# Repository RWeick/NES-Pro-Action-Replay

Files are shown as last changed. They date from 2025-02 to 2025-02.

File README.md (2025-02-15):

# NES-Pro-Action-Replay
Everything necessary to produce the Pro Action Replay for the NES. Happy making.

The PAL's logic decodes to:

/SRAM.CS1.OE = ROMSEL.Sys and Addr: 0x5000 - 0x5FFF

/CPU_FF_CLK = /ROMSEL.Sys and PPU_EN and Addr: 0x7FFA

/PPU_FF_CLK = /ROMSEL.Sys and Addr: 0x7FF8

PCB Thickness: 1.6 mm

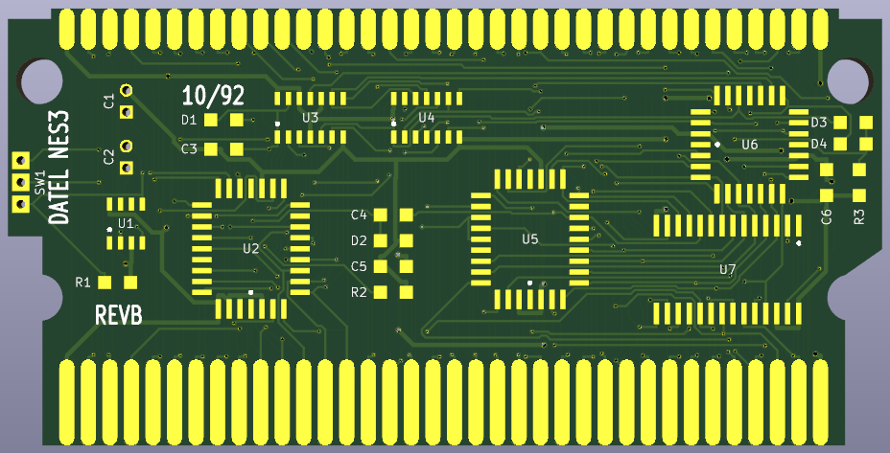
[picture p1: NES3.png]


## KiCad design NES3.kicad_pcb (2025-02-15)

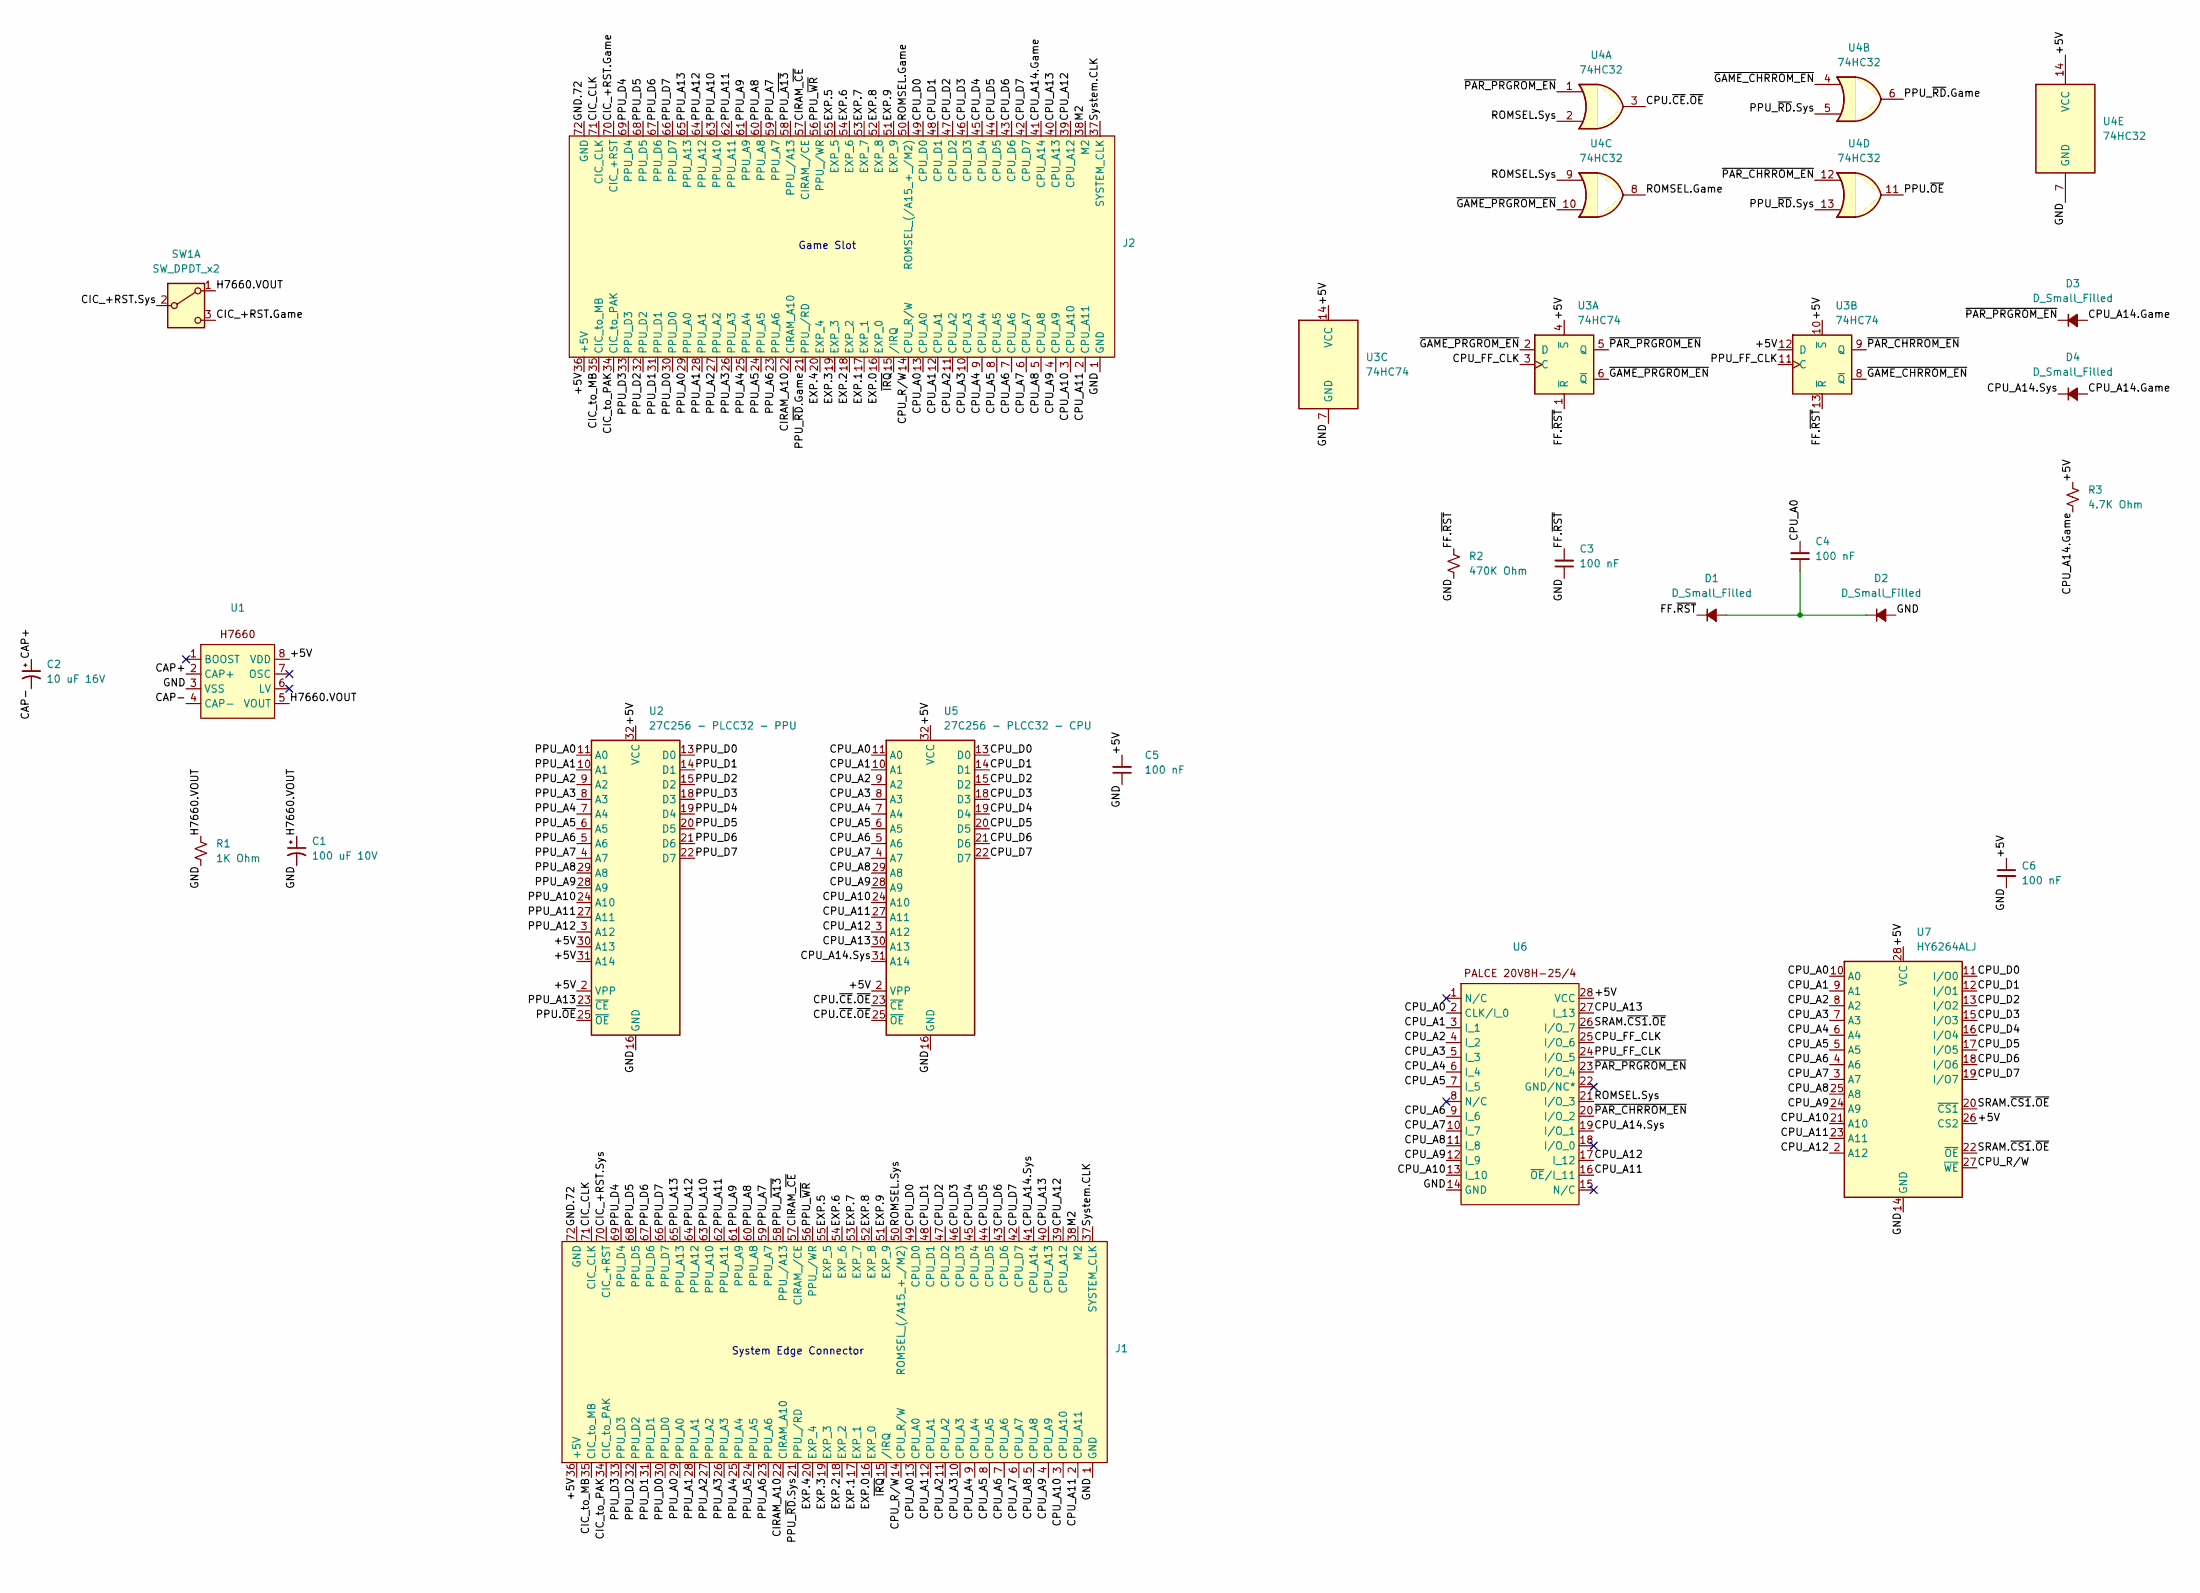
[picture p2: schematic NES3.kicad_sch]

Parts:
C1: 100 uF 10V; THT Caps
C2: 10 uF 16V; THT Caps
C3, C4, C5, C6: 100 nF; SMD Passive
D1, D2, D3, D4: D_Small_Filled; SMD Passive
J1: System Edge Connector
J2: Game Cartridge Slot
R1: 1K Ohm; SMD Passive
R2: 470K Ohm; SMD Passive
R3: 4.7K Ohm; SMD Passive
SW1: SW_DPDT_x2; Switch
U1: SOP-8
U2: 27C256 - PLCC32 - PPU; 27C256
U3: 74HC74; SOP-14
U4: 74HC32; SOP-14
U5: 27C256 - PLCC32 - CPU; 27C256
U6: PLCC-28
U7: HY6264ALJ; SRAM

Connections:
/+5V: C5.2, C6.1, J1.36 (+5V), J2.36 (+5V), R3.1, U1.8 (VDD), U2.2 (VPP), U2.30 (A13), U2.31 (A14), U2.32 (VCC), U3.4 (~S), U3.10 (~S), U3.12 (D), U3.14 (VCC), U4.14 (VCC), U5.2 (VPP), U5.32 (VCC), U6.28 (VCC), U7.26 (CS2), U7.28 (VCC)
/CAP+: C2.1, U1.2 (CAP+)
/CAP-: C2.2, U1.4 (CAP-)
/CIC_+RST.Game: J2.70 (CIC_+RST), SW1.3 (C)
/CIC_+RST.Sys: J1.70 (CIC_+RST), SW1.2 (B)
/CIC_CLK: J1.71 (CIC_CLK), J2.71 (CIC_CLK)
/CIC_to_MB: J1.35 (CIC_to_MB), J2.35 (CIC_to_MB)
/CIC_to_PAK: J1.34 (CIC_to_PAK), J2.34 (CIC_to_PAK)
/CIRAM_A10: J1.22 (CIRAM_A10), J2.22 (CIRAM_A10)
/CIRAM_~CE: J1.57 (CIRAM_/CE), J2.57 (CIRAM_/CE)
/CPU.~CE.~OE: U4.3, U5.23 (~CE), U5.25 (~OE)
/CPU_A0: C4.2, J1.13 (CPU_A0), J2.13 (CPU_A0), U5.11 (A0), U6.2 (CLK/I_0), U7.10 (A0)
/CPU_A1: J1.12 (CPU_A1), J2.12 (CPU_A1), U5.10 (A1), U6.3 (I_1), U7.9 (A1)
/CPU_A2: J1.11 (CPU_A2), J2.11 (CPU_A2), U5.9 (A2), U6.4 (I_2), U7.8 (A2)
/CPU_A3: J1.10 (CPU_A3), J2.10 (CPU_A3), U5.8 (A3), U6.5 (I_3), U7.7 (A3)
/CPU_A4: J1.9 (CPU_A4), J2.9 (CPU_A4), U5.7 (A4), U6.6 (I_4), U7.6 (A4)
/CPU_A5: J1.8 (CPU_A5), J2.8 (CPU_A5), U5.6 (A5), U6.7 (I_5), U7.5 (A5)
/CPU_A6: J1.7 (CPU_A6), J2.7 (CPU_A6), U5.5 (A6), U6.9 (I_6), U7.4 (A6)
/CPU_A7: J1.6 (CPU_A7), J2.6 (CPU_A7), U5.4 (A7), U6.10 (I_7), U7.3 (A7)
/CPU_A8: J1.5 (CPU_A8), J2.5 (CPU_A8), U5.29 (A8), U6.11 (I_8), U7.25 (A8)
/CPU_A9: J1.4 (CPU_A9), J2.4 (CPU_A9), U5.28 (A9), U6.12 (I_9), U7.24 (A9)
/CPU_A10: J1.3 (CPU_A10), J2.3 (CPU_A10), U5.24 (A10), U6.13 (I_10), U7.21 (A10)
/CPU_A11: J1.2 (CPU_A11), J2.2 (CPU_A11), U5.27 (A11), U6.16 (~OE/I_11), U7.23 (A11)
/CPU_A12: J1.39 (CPU_A12), J2.39 (CPU_A12), U5.3 (A12), U6.17 (I_12), U7.2 (A12)
/CPU_A13: J1.40 (CPU_A13), J2.40 (CPU_A13), U5.30 (A13), U6.27 (I_13)
/CPU_A14.Game: D3.2 (A), D4.2 (A), J2.41 (CPU_A14), R3.2
/CPU_A14.Sys: D4.1 (K), J1.41 (CPU_A14), U5.31 (A14), U6.19 (I/O_1)
/CPU_D0: J1.49 (CPU_D0), J2.49 (CPU_D0), U5.13 (D0), U7.11 (I/O0)
/CPU_D1: J1.48 (CPU_D1), J2.48 (CPU_D1), U5.14 (D1), U7.12 (I/O1)
/CPU_D2: J1.47 (CPU_D2), J2.47 (CPU_D2), U5.15 (D2), U7.13 (I/O2)
/CPU_D3: J1.46 (CPU_D3), J2.46 (CPU_D3), U5.18 (D3), U7.15 (I/O3)
/CPU_D4: J1.45 (CPU_D4), J2.45 (CPU_D4), U5.19 (D4), U7.16 (I/O4)
/CPU_D5: J1.44 (CPU_D5), J2.44 (CPU_D5), U5.20 (D5), U7.17 (I/O5)
/CPU_D6: J1.43 (CPU_D6), J2.43 (CPU_D6), U5.21 (D6), U7.18 (I/O6)
/CPU_D7: J1.42 (CPU_D7), J2.42 (CPU_D7), U5.22 (D7), U7.19 (I/O7)
/CPU_FF_CLK: U3.3 (C), U6.25 (I/O_6)
/CPU_R/W: J1.14 (CPU_R/W), J2.14 (CPU_R/W), U7.27 (~WE)
/EXP.0: J1.16 (EXP_0), J2.16 (EXP_0)
/EXP.1: J1.17 (EXP_1), J2.17 (EXP_1)
/EXP.2: J1.18 (EXP_2), J2.18 (EXP_2)
/EXP.3: J1.19 (EXP_3), J2.19 (EXP_3)
/EXP.4: J1.20 (EXP_4), J2.20 (EXP_4)
/EXP.5: J1.55 (EXP_5), J2.55 (EXP_5)
/EXP.6: J1.54 (EXP_6), J2.54 (EXP_6)
/EXP.7: J1.53 (EXP_7), J2.53 (EXP_7)
/EXP.8: J1.52 (EXP_8), J2.52 (EXP_8)
/EXP.9: J1.51 (EXP_9), J2.51 (EXP_9)
/FF.~RST: C3.2, D1.1 (K), R2.1, U3.1 (~R), U3.13 (~R)
/GND: C1.2, C3.1, C5.1, C6.2, D2.2 (A), J1.1 (GND), J2.1 (GND), R1.2, R2.2, U1.3 (VSS), U2.16 (GND), U3.7 (GND), U4.7 (GND), U5.16 (GND), U6.14 (GND), U7.14 (GND)
/GND.72: J1.72 (GND), J2.72 (GND)
/H7660.VOUT: C1.1, R1.1, SW1.1 (A), U1.5 (VOUT)
/M2: J1.38 (M2), J2.38 (M2)
/PPU.~OE: U2.25 (~OE), U4.11
/PPU_A0: J1.29 (PPU_A0), J2.29 (PPU_A0), U2.11 (A0)
/PPU_A1: J1.28 (PPU_A1), J2.28 (PPU_A1), U2.10 (A1)
/PPU_A2: J1.27 (PPU_A2), J2.27 (PPU_A2), U2.9 (A2)
/PPU_A3: J1.26 (PPU_A3), J2.26 (PPU_A3), U2.8 (A3)
/PPU_A4: J1.25 (PPU_A4), J2.25 (PPU_A4), U2.7 (A4)
/PPU_A5: J1.24 (PPU_A5), J2.24 (PPU_A5), U2.6 (A5)
/PPU_A6: J1.23 (PPU_A6), J2.23 (PPU_A6), U2.5 (A6)
/PPU_A7: J1.59 (PPU_A7), J2.59 (PPU_A7), U2.4 (A7)
/PPU_A8: J1.60 (PPU_A8), J2.60 (PPU_A8), U2.29 (A8)
/PPU_A9: J1.61 (PPU_A9), J2.61 (PPU_A9), U2.28 (A9)
/PPU_A10: J1.63 (PPU_A10), J2.63 (PPU_A10), U2.24 (A10)
/PPU_A11: J1.62 (PPU_A11), J2.62 (PPU_A11), U2.27 (A11)
/PPU_A12: J1.64 (PPU_A12), J2.64 (PPU_A12), U2.3 (A12)
/PPU_A13: J1.65 (PPU_A13), J2.65 (PPU_A13), U2.23 (~CE)
/PPU_D0: J1.30 (PPU_D0), J2.30 (PPU_D0), U2.13 (D0)
/PPU_D1: J1.31 (PPU_D1), J2.31 (PPU_D1), U2.14 (D1)
/PPU_D2: J1.32 (PPU_D2), J2.32 (PPU_D2), U2.15 (D2)
/PPU_D3: J1.33 (PPU_D3), J2.33 (PPU_D3), U2.18 (D3)
/PPU_D4: J1.69 (PPU_D4), J2.69 (PPU_D4), U2.19 (D4)
/PPU_D5: J1.68 (PPU_D5), J2.68 (PPU_D5), U2.20 (D5)
/PPU_D6: J1.67 (PPU_D6), J2.67 (PPU_D6), U2.21 (D6)
/PPU_D7: J1.66 (PPU_D7), J2.66 (PPU_D7), U2.22 (D7)
/PPU_FF_CLK: U3.11 (C), U6.24 (I/O_5)
/PPU_~A13: J1.58 (PPU_/A13), J2.58 (PPU_/A13)
/PPU_~RD.Game: J2.21 (PPU_/RD), U4.6
/PPU_~RD.Sys: J1.21 (PPU_/RD), U4.5, U4.13
/PPU_~WR: J1.56 (PPU_/WR), J2.56 (PPU_/WR)
/ROMSEL.Game: J2.50 (ROMSEL_(/A15_+_/M2)), U4.8
/ROMSEL.Sys: J1.50 (ROMSEL_(/A15_+_/M2)), U4.2, U4.9, U6.21 (I/O_3)
/SRAM.~CS1.~OE: U6.26 (I/O_7), U7.20 (~CS1), U7.22 (~OE)
/System.CLK: J1.37 (SYSTEM_CLK), J2.37 (SYSTEM_CLK)
/~GAME_CHRROM_EN: U3.8 (~Q), U4.4
/~GAME_PRGROM_EN: U3.2 (D), U3.6 (~Q), U4.10
/~IRQ: J1.15 (/IRQ), J2.15 (/IRQ)
/~PAR_CHRROM_EN: U3.9 (Q), U4.12, U6.20 (I/O_2)
/~PAR_PRGROM_EN: D3.1 (K), U3.5 (Q), U4.1, U6.23 (I/O_4)
unnamed: C4.1, D1.2 (A), D2.1 (K)

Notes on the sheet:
System Edge Connector
Game Slot

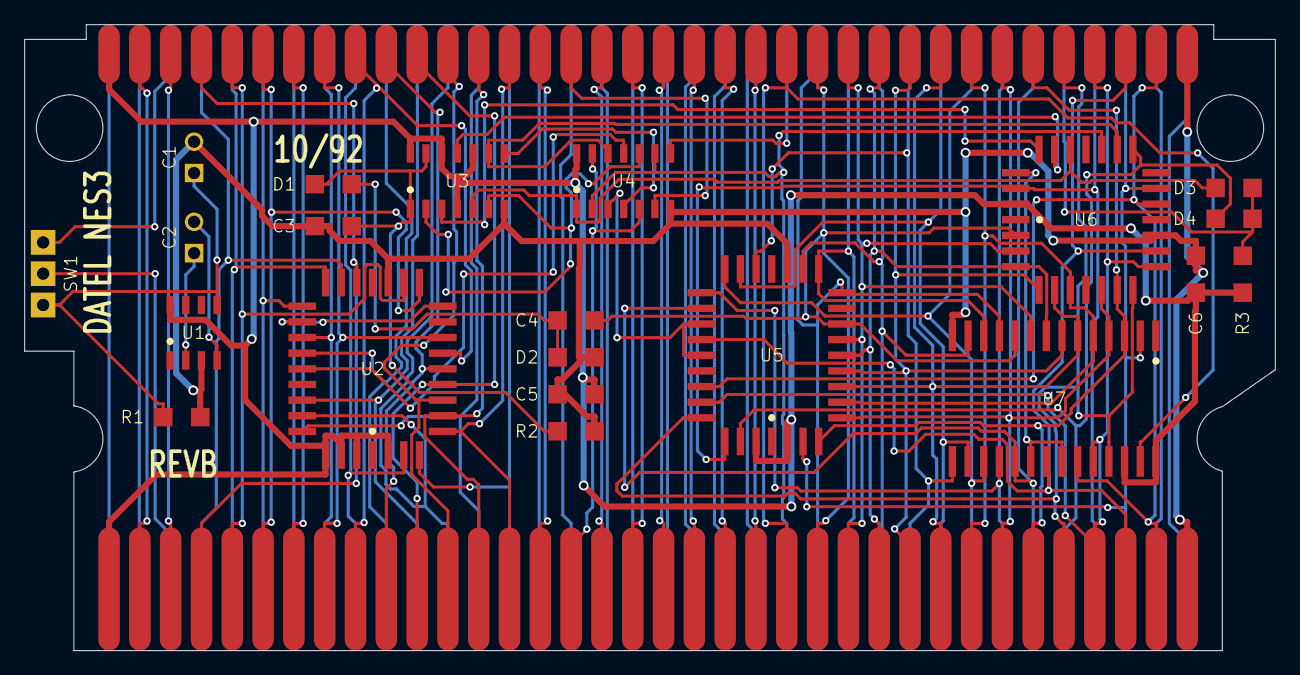
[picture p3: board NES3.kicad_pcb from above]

Board: 2 copper layers, 101.5 x 50.8 mm, 23 parts (0 on the bottom side), 90 nets.
